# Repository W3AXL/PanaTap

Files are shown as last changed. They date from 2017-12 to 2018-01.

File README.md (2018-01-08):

# PanaTap
Updated G4HUP panadapter tap

Simple revision to the G4HUP high-impedance IF tap with specific components and updated filters.

History

12/14/2017
 - Revised parts.md to add quantity of parts needed.

12/10/2017
 - Up and running on a Yaesu FT-991A

12/10/2017
 - Revised component values to values that you can actually obtain. Added digikey parts list.

10/22/2017
 - Second revision testing complete and satisfactory. Up and running on a Yaesu FT-450D

08/30/2017
 - Schematic revised to fix capacitor placement error in original schematic. New boards sent out for fabrication and testing will be done when they get back.

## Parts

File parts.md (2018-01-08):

Digikey Parts List for Panatap

| Qty | Part | Digikey Part no |
| --- | --- | --- |
| 2 | CAP 0.1uF | 399-1249-1-ND |
| 3 | CAP 0.1nF | 399-8131-1-ND |
| 1 | CAP 68pF | 399-1204-1-ND |
| 2 | CAP 56pF | 399-1203-1-ND |
| 1 | RES 100k | 	541-100KECT-ND |
| 1 | RES 100 | 	541-100ECT-ND |
| 1 | RES 39K | 	541-39KECT-ND |
| 1 | RES 220| 541-220ECT-ND |
| 2 | RES 1k | 541-1.0KECT-ND |
| 1 | JFET J310 | MMBFJ310CT-ND |
| 1 | RF NPN BFS17 | BFS17PE6327HTSA1CT-ND |
| 2 | IND 82nH | 	445-1034-1-ND |
| 2 | IND 180nH | 	445-8986-1-ND |

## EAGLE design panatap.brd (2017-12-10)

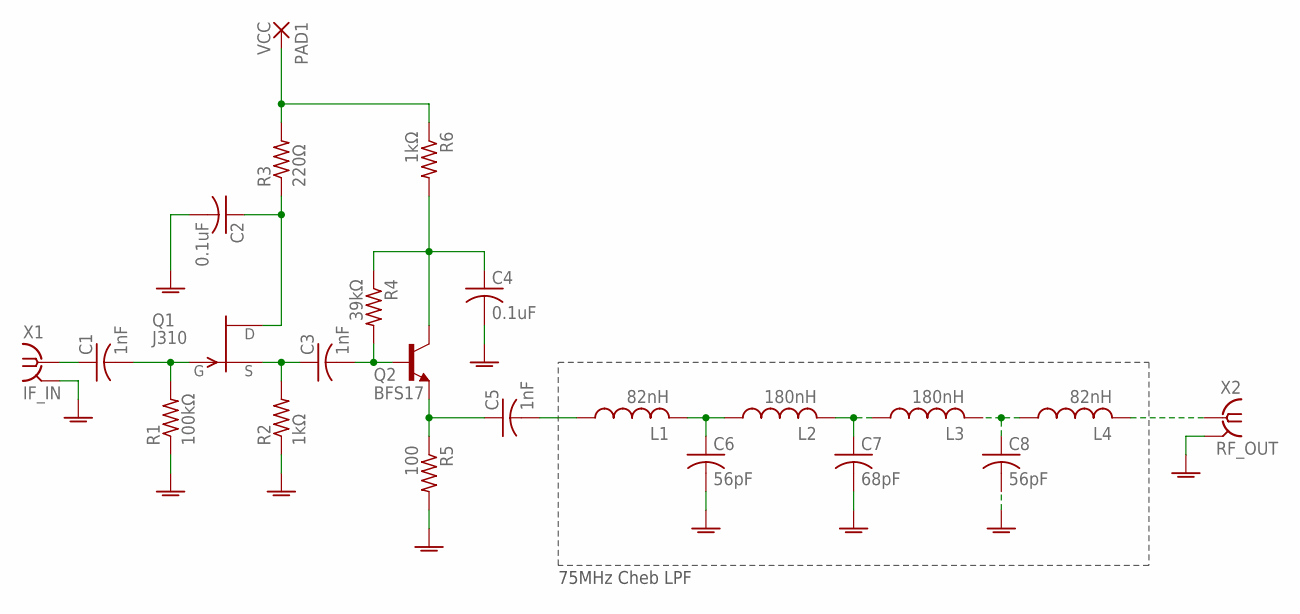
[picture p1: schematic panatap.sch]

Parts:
C1, C3, C5: 1nF; C1206
C2, C4: 0.1uF; C1206
C6, C8: 56pF; C1206
C7: 68pF; C1206
L1, L4: 82nH; L2012C
L2, L3: 180nH; L2012C
PAD1: VCC; SMD2,54-5,08
Q1: J310; SOT23
Q2: BFS17; SOT23
R1: 100kΩ; R1206
R2, R6: 1kΩ; R1206
R3: 220Ω; R1206
R4: 39kΩ; R1206
R5: 100; R1206
X1: IF_IN; J502-ND-142-0701-801/806
X2: RF_OUT; J502-ND-142-0701-801/806

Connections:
GNDA: C2.2, C4.2, C6.2, C7.2, C8.2, R1.1, R2.1, R5.2, X1.G@1 (2), X1.G@2 (2), X1.G@3 (2), X1.G@4 (2), X2.G@1 (2), X2.G@2 (2), X2.G@3 (2), X2.G@4 (2)
unnamed: C5.1, Q2.2 (E), R5.1
unnamed: C5.2, L1.1
unnamed: C6.1, L1.2, L2.1
unnamed: C3.2, Q2.1 (B), R4.2
unnamed: C3.1, Q1.2 (S), R2.2
unnamed: C1.2, Q1.3 (G), R1.2
unnamed: C1.1, X1.1
unnamed: PAD1.1, R3.2, R6.1
unnamed: C2.1, Q1.1 (D), R3.1
unnamed: C4.1, Q2.3 (C), R4.1, R6.2
unnamed: C7.1, L2.2, L3.1
unnamed: L4.2, X2.1
unnamed: C8.1, L3.2, L4.1

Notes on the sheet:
75MHz Cheb LPF

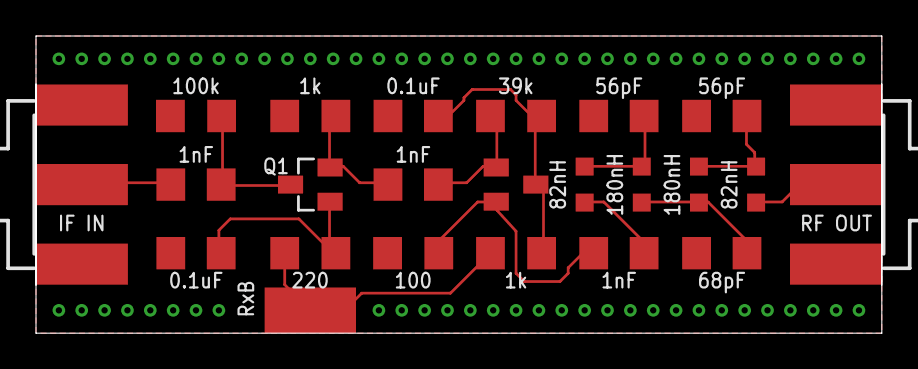
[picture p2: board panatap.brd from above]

Board: 2 copper layers, 47.0 x 16.5 mm, 23 parts (0 on the bottom side), 14 nets.

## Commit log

2017-08-31 Updated schematic and board with revised capacitor placement
    [panatap.brd, panatap.sch]
2017-12-10 filter values changed, LTSpice added
    filter values changed to real, obtainable components and added LTSpice simulation file
    [panatap.brd, panatap.sch]
